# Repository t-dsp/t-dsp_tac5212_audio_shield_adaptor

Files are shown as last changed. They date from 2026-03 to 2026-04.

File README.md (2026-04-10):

# T-DSP TAC5212 Audio Shield Adaptor for Teensy 4.1

**Part of the [T-DSP](https://t-dsp.com) open modular audio platform.**

A compact carrier board (60.93mm × 26.46mm) that connects a [T-DSP TAC5212 audio module](https://github.com/t-dsp) and a [Teensy 4.1](https://www.pjrc.com/teensy/) together into a simple, USB-powered Teensy audio shield — with stereo line in/out, two onboard PDM MEMS microphones, USB Host, and SD card access.

T-DSP TAC5212 Audio Shield Adaptor - Top Isometric

| | |
|:---:|:---:|
| Top | Bottom |
| Front | Rear |

**[View 3D Render Gallery](https://t-dsp.github.io/t-dsp_tac5212_audio_shield_adaptor/gallery.html)** -- interactive slideshow of all board views

## Assembled Hardware

| | |
|:---:|:---:|
| Top view of the assembled stack | Side view of the assembled stack |
| Top — TAC5212 module on the adaptor | Side — adaptor + Teensy 4.1 + TAC5212 module |

## What It Is

This is the simplest board in the T-DSP ecosystem. It is an **adaptor** — a small carrier PCB that brings together two modules:

- **[T-DSP TAC5212 module](https://github.com/t-dsp)** — the pro audio codec daughter board (plugs into the adaptor via headers)
- **[Teensy 4.1](https://www.pjrc.com/teensy/)** — ARM Cortex-M7 running the [Teensy Audio Library](https://www.pjrc.com/teensy/td_libs_Audio.html)

The result is a compact, bus-powered audio shield with stereo line I/O, two MEMS microphones, USB Host, and SD card access — no external power supply required.

## What You Need

| Item | Notes |
|---|---|
| T-DSP TAC5212 audio module | Plugs into the adaptor's module connector |
| Teensy 4.1 | Socketed onto the adaptor's Teensy headers |
| This adaptor PCB | The carrier board documented here |

Power comes from the Teensy 4.1's USB connector — no external supply needed.

## Features

### Audio I/O
- **Stereo line input** -- via the TAC5212 module's ADC
- **Stereo line output** -- via the TAC5212 module's DAC
- **2× PDM MEMS microphones** -- Knowles SPK0641HT4H-1, speakerphone-grade, for voice capture or stereo room mics

### Connectivity
- **USB Host** -- USB-A host port for MIDI controllers, USB storage, and USB audio devices
- **SD card** -- Accessible via the Teensy 4.1's built-in SD slot

### Power
- **USB via Teensy 4.1** -- Bus-powered from the Teensy's USB port; no additional power input on this board

## Board Design

- **60.93mm × 26.46mm** PCB
- Designed around the T-DSP audio module board outline standard
- The TAC5212 module handles the entire analog signal path
- KiCad source files, full BOM, and CI-generated manufacturing outputs included
- Open source under CC BY-NC-SA 4.0

## Getting Started

### Hardware

1. Solder pin headers on your **Teensy 4.1** (if not already done)
2. Socket the Teensy 4.1 into the adaptor board headers
3. Plug the **TAC5212 module** into its connector on the adaptor
4. Connect your line-level audio source and output to the TAC5212 module's jacks
5. Connect USB to the Teensy 4.1 for power and optionally USB Audio

### Firmware

Working firmware lives in the **[T-DSP Software](https://github.com/t-dsp/t-dsp_software)** repository, in the [`projects/t-dsp_tac5212_audio_shield_adaptor`](https://github.com/t-dsp/t-dsp_software/tree/master/projects/t-dsp_tac5212_audio_shield_adaptor) folder. It's a PlatformIO project that gives you:

- **USB Audio class device** — the Teensy enumerates as a stereo soundcard on the host
- **Stereo playback** — host audio plays through the TAC5212 DAC out
- **PDM mic + line-in capture** — both onboard PDM mics and the line input are mixed into the host recording stream
- **Live monitoring** — toggle PDM mic and/or line input through the headphone output via simple serial commands
- **Host volume tracking** — the OS playback volume slider directly controls the TAC5212 DAC digital volume

To build and flash:

```bash
git clone https://github.com/t-dsp/t-dsp_software.git
cd t-dsp_software/projects/t-dsp_tac5212_audio_shield_adaptor
python -m platformio run --target upload
```

See the [project README](https://github.com/t-dsp/t-dsp_software/tree/master/projects/t-dsp_tac5212_audio_shield_adaptor) for the full setup walkthrough, audio routing diagram, and serial command reference. New to PlatformIO? Start with the [hello-world setup guide](https://github.com/t-dsp/t-dsp_software/tree/master/projects/hello-world).

View the design files in your browser with KiCanvas: [Schematic](https://kicanvas.org/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) | [PCB](https://kicanvas.org/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)

## Project Files

| Directory | Contents |
|---|---|
| `/3d_models/` | 3D models for PCB components |
| `/lib_fp/` | Custom KiCad footprint libraries |
| `/lib_sch/` | Custom KiCad schematic symbol libraries |
| `/manufacturing/` | CI-generated manufacturing outputs (gerbers, BOM, pick & place, PDFs) |
| `/pages/` | [3D Render Gallery](https://t-dsp.github.io/t-dsp_tac5212_audio_shield_adaptor/gallery.html), [Interactive BOM](https://t-dsp.github.io/t-dsp_tac5212_audio_shield_adaptor/ibom.html) |

## Manufacturing

Manufacturing files are generated automatically by [KiBot](https://github.com/INTI-CMNB/KiBot) on every push to `main` and on tagged releases via GitHub Actions.

To order:
1. Download the latest `t-dsp_tac5212_audio_shield_adaptor-manufacturing-vX.X.X.zip` from [Releases](https://github.com/t-dsp/t-dsp_tac5212_audio_shield_adaptor/releases)
2. Upload gerbers and drill files to your PCB fab (JLCPCB, PCBWay, etc.)
3. Use the BOM and CPL files for JLCPCB SMT assembly

## About T-DSP

T-DSP is an open modular audio platform built around the Teensy microcontroller and the [Teensy Audio Library](https://www.pjrc.com/teensy/td_libs_Audio.html). This adaptor is the simplest entry point — a small carrier that turns a Teensy 4.1 and a TAC5212 module into a working audio shield.

For a full desktop audio development platform with ESP32 UI, MIDI I/O, S/PDIF, RCA I/O, and multi-module TDM expansion, see the [T-DSP Desktop Pro](https://github.com/t-dsp/t-dsp_desktop_pro).

Learn more at [t-dsp.com](https://t-dsp.com).

## Status

Active development. If you build one, please open an issue or reach out.

## Contact

For consulting, custom audio hardware design, or commercial licensing, reach out via [LinkedIn](https://linkedin.com/in/jayshoe).

## License

[Creative Commons Attribution-NonCommercial-ShareAlike 4.0 International (CC BY-NC-SA 4.0)](https://creativecommons.org/licenses/by-nc-sa/4.0/)

Free to share and adapt for non-commercial purposes with attribution and same license on derivatives.

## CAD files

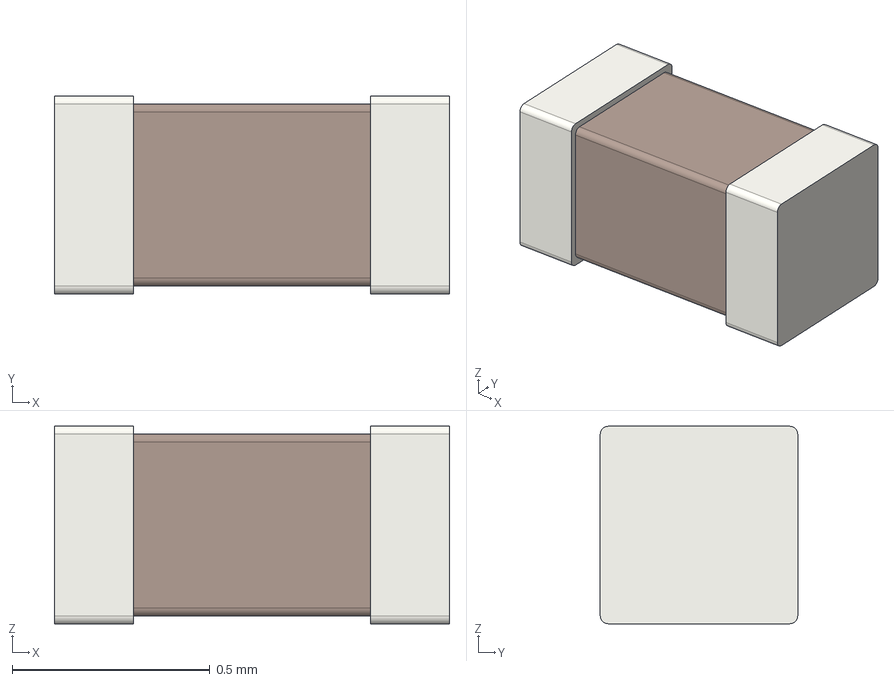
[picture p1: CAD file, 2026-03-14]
3d_models/C_0402_1005Metric.step
1.00 x 0.5 x 0.5 mm

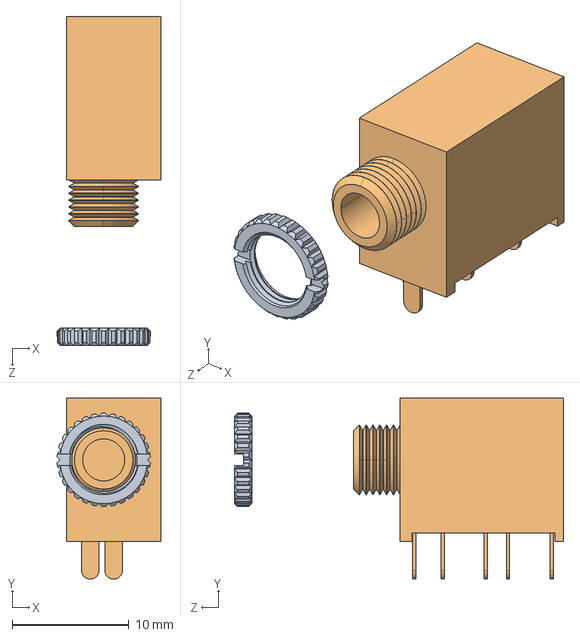
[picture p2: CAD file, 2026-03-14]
3d_models/35RAPC4BV4.step
8.89 x 15.5 x 28.2 mm

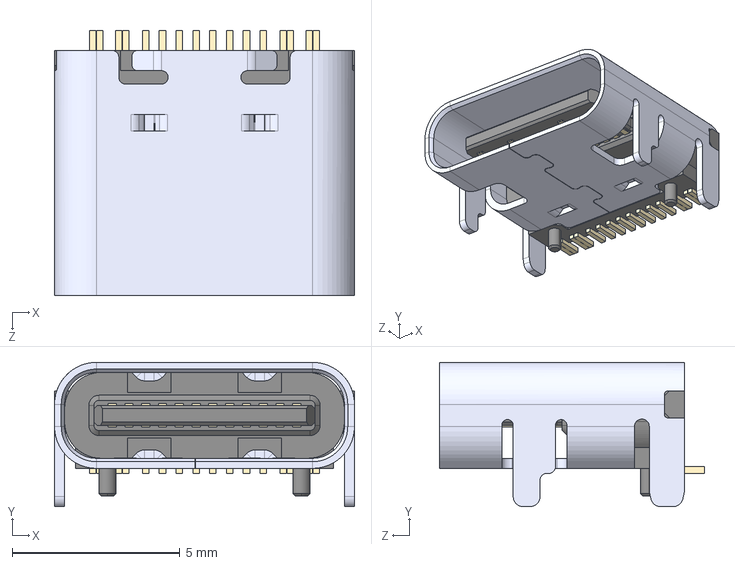
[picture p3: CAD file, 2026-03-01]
lib_fp/project_fp/TYPE-C-31-M-12.step
8.94 x 4.30 x 7.90 mm

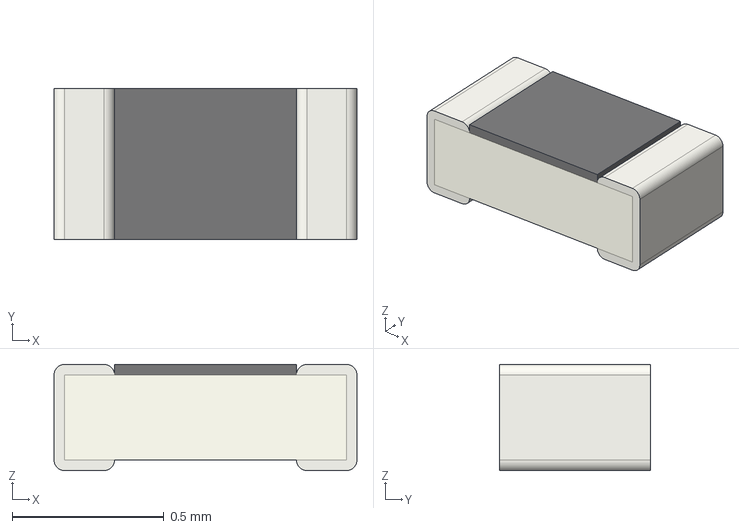
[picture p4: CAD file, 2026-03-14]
3d_models/R_0402_1005Metric.step
1.00 x 0.5 x 0.35 mm

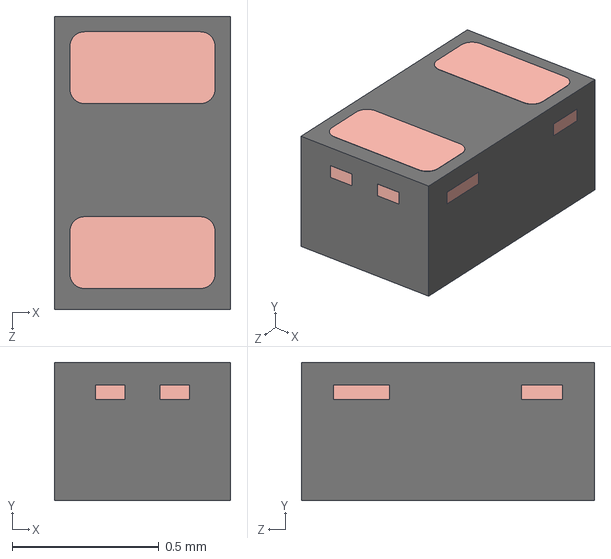
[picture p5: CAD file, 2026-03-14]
3d_models/PESD5V0F1BL_315.stp
0.6 x 0.471 x 1.00 mm
SOD882 body
SOD882A3 singulated LF unit

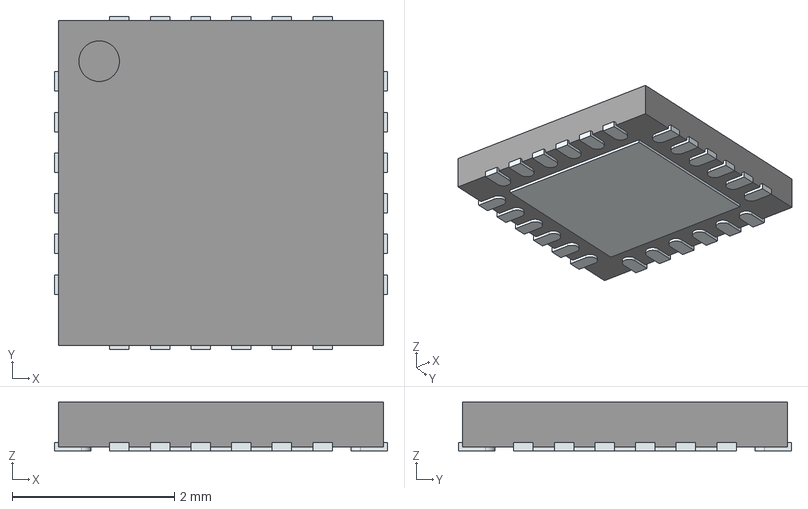
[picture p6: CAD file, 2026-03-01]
lib_fp/project_fp/CYPD3177-24LQXQ.stp
4.10 x 4.10 x 0.6 mm
ThermalPin
PinsArrayLR
PinsArrayTB

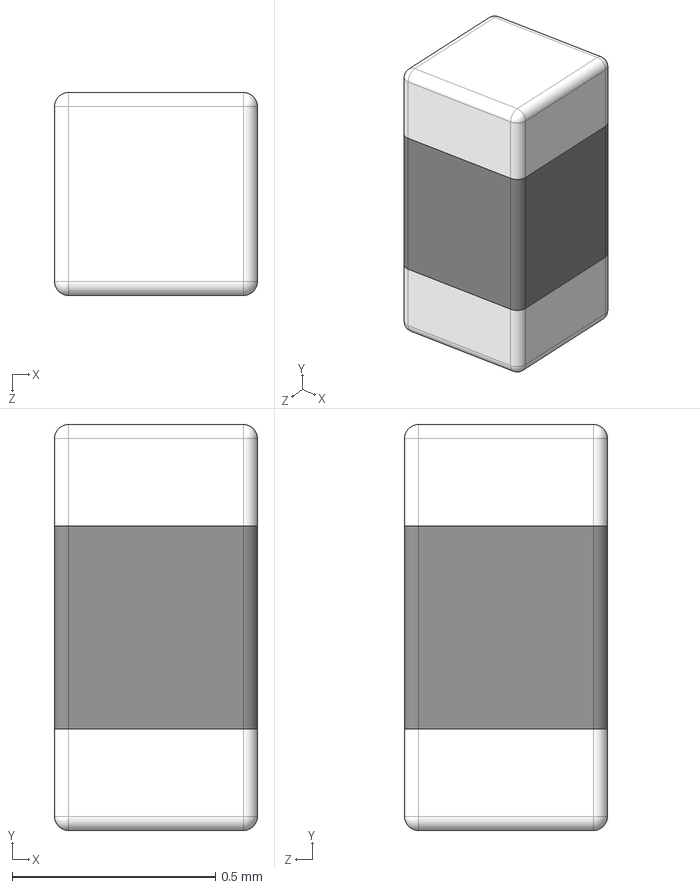
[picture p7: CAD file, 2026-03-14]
3d_models/BLM15AG601SN1D.stp
0.5 x 1.00 x 0.5 mm

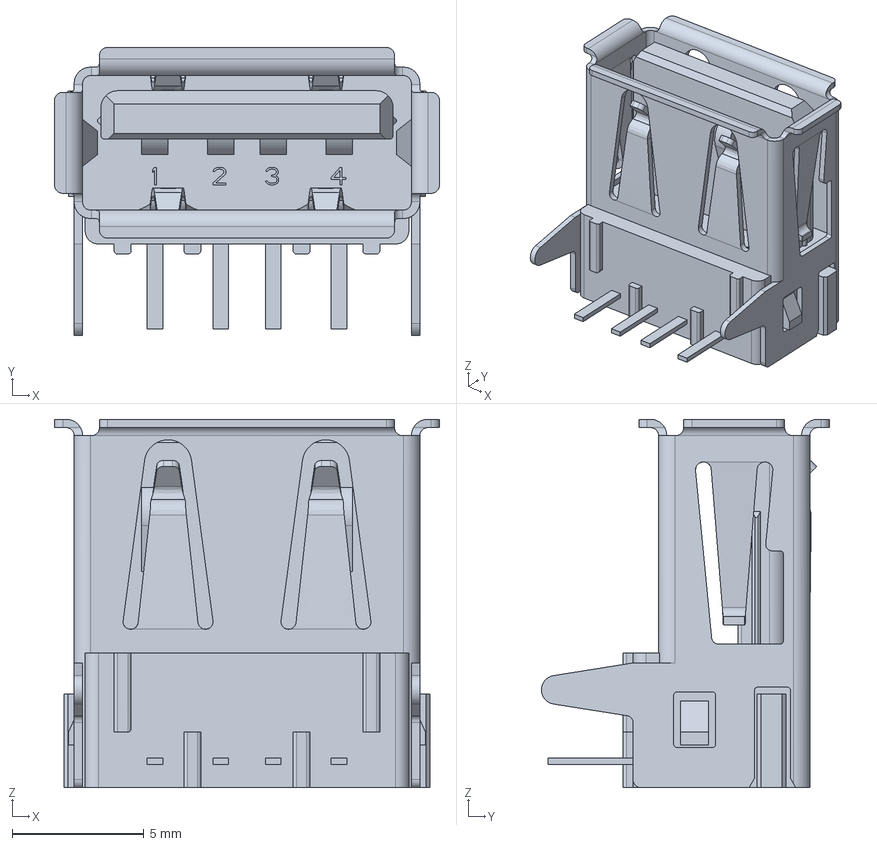
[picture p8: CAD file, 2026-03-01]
3d_models/c-6364372-2-o-3d.stp
14.6 x 10.9 x 14.0 mm

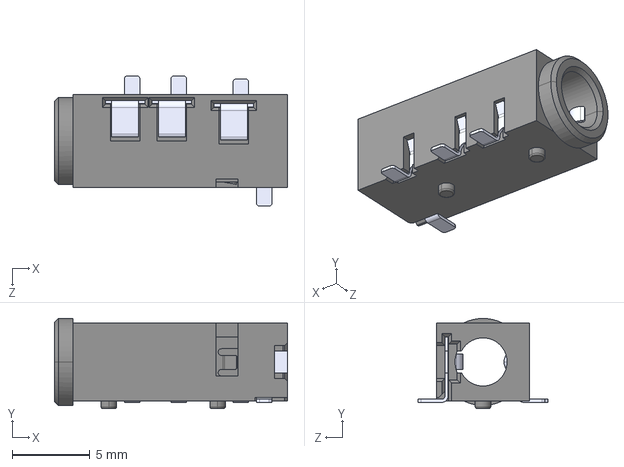
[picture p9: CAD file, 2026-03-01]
3d_models/SJ2-3574A-SMT-TR.step
15.0 x 5.80 x 8.40 mm

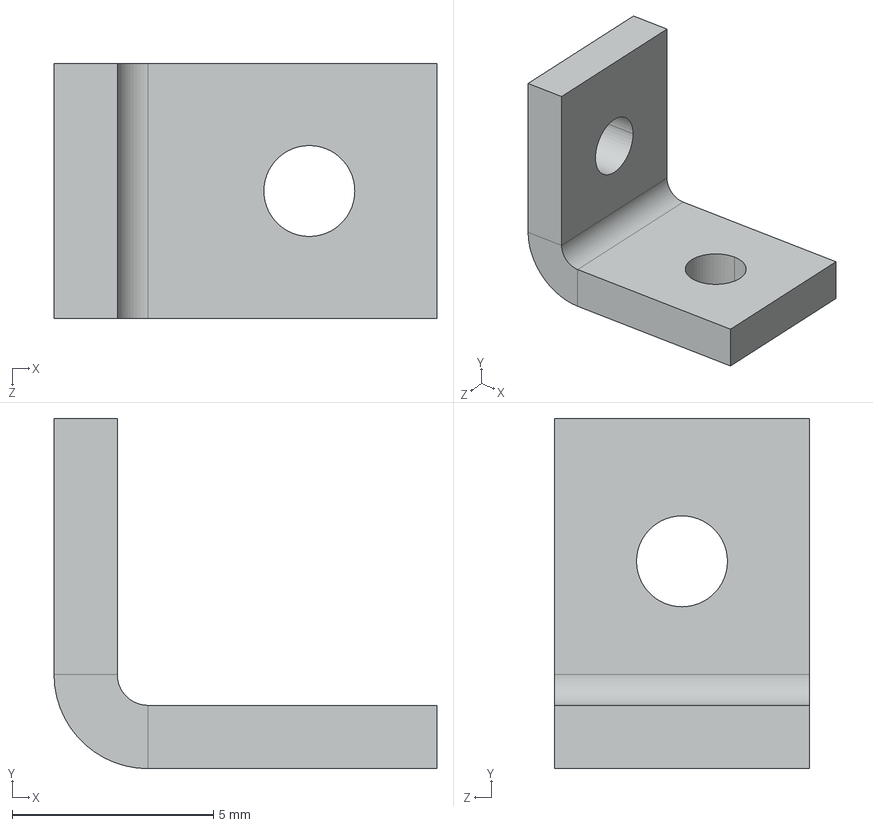
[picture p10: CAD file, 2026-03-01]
3d_models/Bracket 4-40 621.STEP
9.53 x 8.71 x 6.35 mm

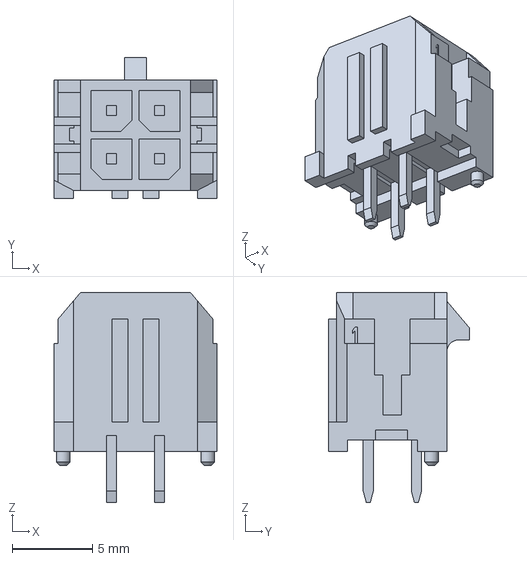
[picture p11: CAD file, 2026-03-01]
3d_models/MicroFit3-43045-0428.stp
10.1 x 8.77 x 13.1 mm

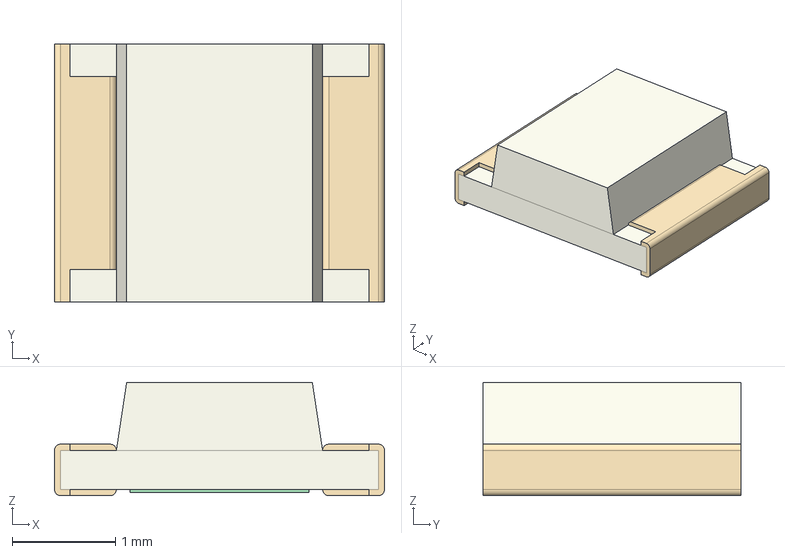
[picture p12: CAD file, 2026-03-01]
3d_models/LED_1210_3225Metric.step
3.20 x 2.50 x 1.10 mm

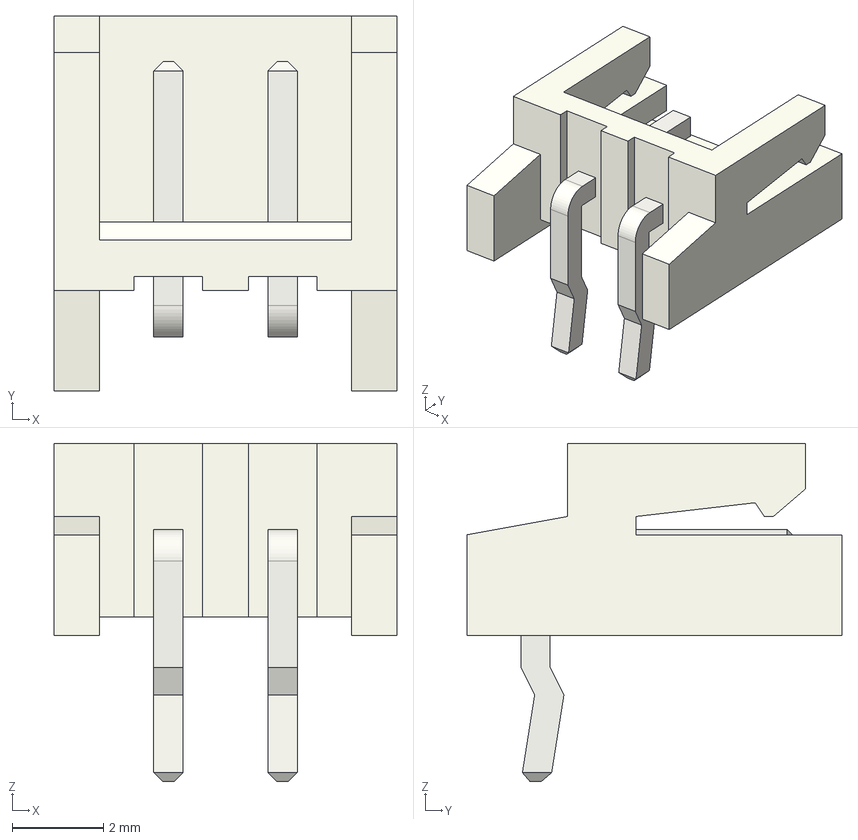
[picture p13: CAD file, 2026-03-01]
3d_models/JST_EH_S2B-EH_1x02_P2.50mm_Horizontal.step
7.50 x 8.20 x 7.40 mm

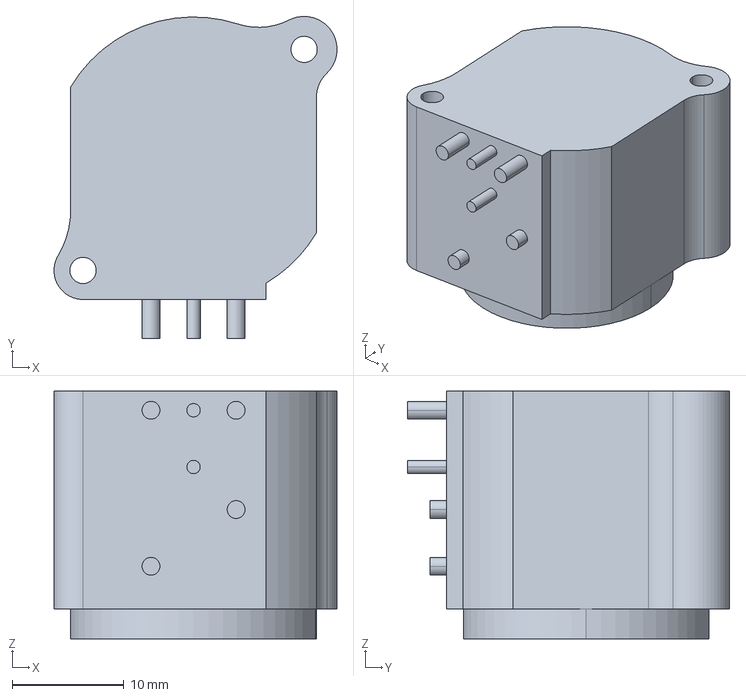
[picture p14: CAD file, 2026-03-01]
3d_models/3-D NC3MAH.stp
25.3 x 28.8 x 22.2 mm

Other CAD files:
3d_models/PinHeader_1x02_P2.54mm_Vertical.step
3d_models/74LS00.step
3d_models/d-nc3fah.stp
3d_models/COMBO_XLR_NCJ6FI-H-0.stp
3d_models/1808--3DModel-STEP-630548.STEP
3d_models/2120--3DModel-STEP-630548.STEP
3d_models/3-D NCJ6FAH.stp
3d_models/3-D NCJ6FI-H-0.stp
3d_models/3-d-nmj6hcd3.stp
3d_models/3.5MM_STEREO_35RAPC4BHN2.STEP
3d_models/35RAPC3BH3.STEP
3d_models/35RAPC7JS.STEP
3d_models/35RAPC7JS_SIMPLIFIED.step
3d_models/3_2SPI-TFT-Modul_ILI9341.STEP
3d_models/4691.step
3d_models/74HCT2G125DC,125.stp
3d_models/COMBO-NCJ6FA-H.step
3d_models/CP_Radial_D10.0mm_P5.00mm.step
3d_models/C_1206_3216Metric.step
3d_models/DC_BARREL_PJ-202AH.step
3d_models/DIN-5.STEP
3d_models/DMG2307L-7.stp
3d_models/D_1210_3225Metric.step
3d_models/EN11-HSM1AF15.STEP
3d_models/FCR6842032R ORJ3.stp
3d_models/FCR6842032T OTJ3.stp
3d_models/H11L1SM.step
3d_models/IDC-Header_2x10_P2.54mm_Vertical.step
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

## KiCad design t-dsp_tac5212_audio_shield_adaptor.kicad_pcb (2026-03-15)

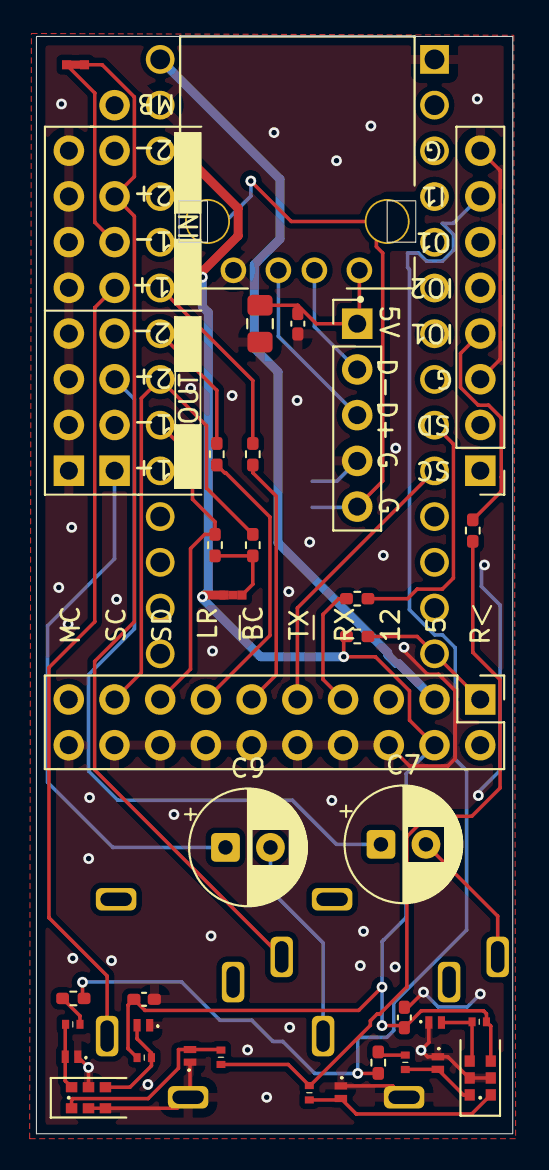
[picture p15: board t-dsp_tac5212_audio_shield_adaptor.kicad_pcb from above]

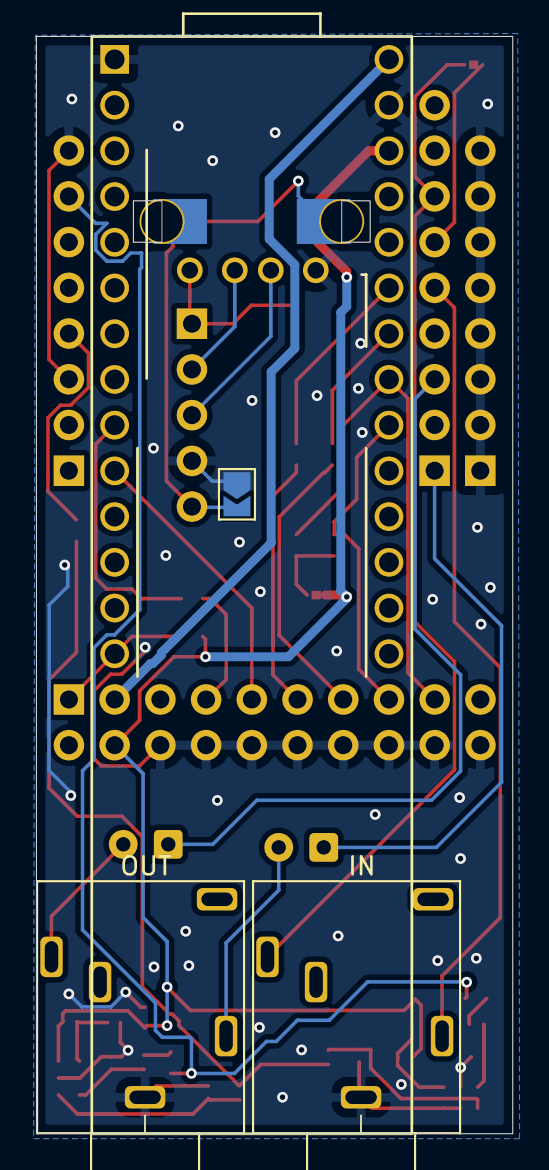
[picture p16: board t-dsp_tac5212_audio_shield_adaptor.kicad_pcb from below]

Board: 2 copper layers, 26.5 x 61.0 mm, 38 parts (4 on the bottom side), 36 nets.

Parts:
C1: 1 uF; C_0402_1005Metric_Pad0.74x0.62mm_HandSolder
C7, C9: 470 uF Electrolytic Audio-Grade; CP_Radial_D6.3mm_P2.50mm
C10, C40: 0.1uF; C_0402_1005Metric_Pad0.74x0.62mm_HandSolder
C33: 10 uF; C_0805_2012Metric_Pad1.15x1.40mm_HandSolder
D6, D7, D8, D9, D10, D11: ESD DIODE; PESD5V0F1BL_315
FB1, FB2, FB3, FB4, FB5, FB6: 600Ω@100MHz; BLM15AG601SN1D
G1: jumper; SolderJumper-2_P1.3mm_Open_TrianglePad1.0x1.5mm
HPTRS1, HPTRS2: 3.5mm TRS - 35RAPC3BH3; 35RAPC3BH3
J21: jumper; jumper_slice
MK1, MK2: MSM261DGT003
R3, R6, R9, R55, R56, R57: 49.9 ohm; R_0402_1005Metric_Pad0.72x0.64mm_HandSolder
R11: 10k; R_0402_1005Metric_Pad0.72x0.64mm_HandSolder
R12: 0 ohm; jumper_slice
R13, R14: 2.21k; R_0402_1005Metric_Pad0.72x0.64mm_HandSolder
U1: Teensy 4.1 - DEVKIT; Teensy41_simple
USBA1: USB A Host - TE 292303-5; TE_292303-5_USB_A_tight_fit
USB_HOST_1: header; USB_IN1
board_outline1: TAC5212 Module; audio_module_board_outline_final_minus-.66_mod_long

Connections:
3.3V: C10.1, C40.1, FB5.1, FB6.1, MK1.6 (SELECT), R11.1, R12.2, U1.46 (3V3), board_outline1.4 (3.3V)
5V: U1.48 (VIN), board_outline1.3 (5V)
7_OUT1A: R3.2, board_outline1.7 (DSP_DOUT)
8_IN1: U1.10 (8_TX2_IN1), board_outline1.9 (DSP_DIN)
35_TX8_RESET: R11.2, U1.14 (12_MISO_MQSL), board_outline1.1 (HELD_HIGH)
/AUDIO_IN1P: HPTRS2.5, board_outline1.29 (IN1P)
/AUDIO_IN2P: HPTRS2.2, J21.1, board_outline1.33 (IN2P)
/AUDIO_OUT2P: C7.1, board_outline1.25 (OUT2P)
/AUDIO_OUTP: C9.1, board_outline1.21 (OUTP)
BCLK1: R6.2, board_outline1.11 (BCLK)
GND: C1.2, C10.2, C33.2, C40.2, D6.1 (K), D7.1 (K), D8.1 (K), D9.1 (K), D10.1 (K), D11.1 (K), G1.1, HPTRS1.1, HPTRS2.1, MK1.2 (GND), MK1.5 (GND), MK2.2 (GND), MK2.5 (GND), MK2.6 (SELECT), U1.1 (GND), U1.47 (GND), USBA1.4 (GND), USB_HOST_1.4 (GND), board_outline1.6 (GNDD), board_outline1.8 (GNDD), board_outline1.10 (GNDD), board_outline1.12 (GNDD), board_outline1.14 (GNDD), board_outline1.16 (GNDD), board_outline1.18 (GNDD), board_outline1.20 (GNDD), board_outline1.22 (AGND), board_outline1.24 (AGND), board_outline1.26 (AGND), board_outline1.28 (AGND), board_outline1.30 (AGND), board_outline1.32 (AGND), board_outline1.34 (AGND), board_outline1.36 (AGND), board_outline1.39 (GNDD), board_outline1.44 (GNDD)
GPIGPI1: R56.1, R57.1, board_outline1.43 (GPI1)
GPIO1: FB3.2, FB4.2, R55.2
HOST_5V: C1.1, C33.1, USBA1.1 (VBUS), USB_HOST_1.1 (5V)
HOST_D1+: USBA1.3 (D+), USB_HOST_1.3 (D1+)
HOST_D1-: USBA1.2 (D-), USB_HOST_1.2 (D1-)
LRCK1: R9.2, board_outline1.13 (LRCK)
unnamed: C7.2, HPTRS1.2
unnamed: C9.2, HPTRS1.5
unnamed: D6.2 (A), FB5.2, MK1.1 (VDD)
unnamed: D7.2 (A), FB6.2, MK2.1 (VDD)
unnamed: D8.2 (A), FB2.2, MK2.3 (DATA)
unnamed: D9.2 (A), FB1.2, MK1.3 (DATA)
unnamed: D10.2 (A), FB3.1, MK2.4 (CLOCK)
unnamed: D11.2 (A), FB4.1, MK1.4 (CLOCK)
unnamed: FB1.1, R57.2
unnamed: FB2.1, R56.2
unnamed: R12.1, R13.2, R14.2
unnamed: R3.1, U1.9 (7_RX2_OUT1A)
unnamed: R9.1, U1.42 (20_A6_TX5_LRCLK1)
unnamed: R6.1, U1.43 (21_A7_RX5_BCLK1)
unnamed: R55.1, board_outline1.40 (GPIO1)
unnamed: J21.2, board_outline1.31 (IN1M)
SCL0: R13.1, U1.41 (19_A5_SCL), board_outline1.17 (SCL)
SDA0: R14.1, U1.40 (18_A4_SDA), board_outline1.15 (SDA)
USB_SHIELD2: G1.2, USBA1.5 (Shield), USB_HOST_1.5 (SHIELD)

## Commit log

2026-03-01 v0.01: Initial release - TAC5212 audio shield adaptor for Teensy 4.1
    Carrier board (60.93mm x 26.46mm) connecting the T-DSP TAC5212 audio
    module and Teensy 4.1 with stereo line in/out, dual PDM MEMS mics
    (SPK0641HT4H-1), USB Host, and SD card access. Bus-powered via Teensy USB-C.
    [1746311-1.step, 1808--3DModel-STEP-630548.STEP, 2120--3DModel-STEP-630548.STEP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]
2026-03-01 Fix: remove inner copper layers from pcb_pdf (2-layer board)
2026-03-02 v0.1: Finish routing, update board outline and revision
    - Complete PCB routing and zone fills
    - Add board outline footprint variants (-0.66mm offset)
    - Update USB-A footprint to KiCad 9.0 format
    - Fix schematic connections and capacitor orientation
    - Correct project filename metadata
    - Update 3D model
    - Set REVISION to v0.1
    [t-dsp_tac5212_audio_shield_adaptor.kicad_pcb, t-dsp_tac5212_audio_shield_adaptor.kicad_sch]
2026-03-10 update usb-a connector
    [t-dsp_tac5212_audio_shield_adaptor.kicad_pcb]
2026-03-10 Update t-dsp_tac5212_audio_shield_adaptor.kicad_sch
    clean up BOM
    [t-dsp_tac5212_audio_shield_adaptor.kicad_sch]
2026-03-10 Update PCB layout
    [t-dsp_tac5212_audio_shield_adaptor.kicad_pcb]
2026-03-14 Add new components, 3D models, and update PCB layout
    Add footprints and symbols for BLM15AG601SN1D, MSM261DGT003,
    PESD5V0F1BL_315, 35RAPC4BV4, and passive 0402 components.
    Add corresponding 3D models. Update schematic, PCB layout,
    and existing footprints.
    [35RAPC4BV4.step, BLM15AG601SN1D.stp, C_0402_1005Metric.step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]
2026-03-15 Fix ESD diode values and R13 value format for BOM correctness
    [t-dsp_tac5212_audio_shield_adaptor.kicad_pcb, t-dsp_tac5212_audio_shield_adaptor.kicad_sch]
2026-04-10 Add assembled hardware photos and link to firmware repo
    - New 'Assembled Hardware' section with top and side photos of the
    fully assembled stack (Teensy 4.1 + adaptor + TAC5212 module)
    - Replace placeholder firmware example with a link to the working
    firmware in t-dsp_software/projects/t-dsp_tac5212_audio_shield_adaptor,
    including a build/flash quickstart and feature summary
    Photos are hosted in the t-dsp_software repo (single source of truth)
    and referenced via raw.githubusercontent.com URLs.

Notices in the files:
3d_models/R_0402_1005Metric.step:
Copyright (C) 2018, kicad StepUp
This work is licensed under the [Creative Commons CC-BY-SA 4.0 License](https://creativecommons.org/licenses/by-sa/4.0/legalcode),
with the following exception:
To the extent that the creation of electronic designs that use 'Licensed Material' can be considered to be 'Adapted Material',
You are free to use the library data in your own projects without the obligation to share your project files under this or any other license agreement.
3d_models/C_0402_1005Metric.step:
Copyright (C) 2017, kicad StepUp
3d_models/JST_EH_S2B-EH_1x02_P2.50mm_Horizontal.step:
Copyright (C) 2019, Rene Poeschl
